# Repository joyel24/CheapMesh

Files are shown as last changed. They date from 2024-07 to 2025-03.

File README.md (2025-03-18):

# CheapMesh
<p>


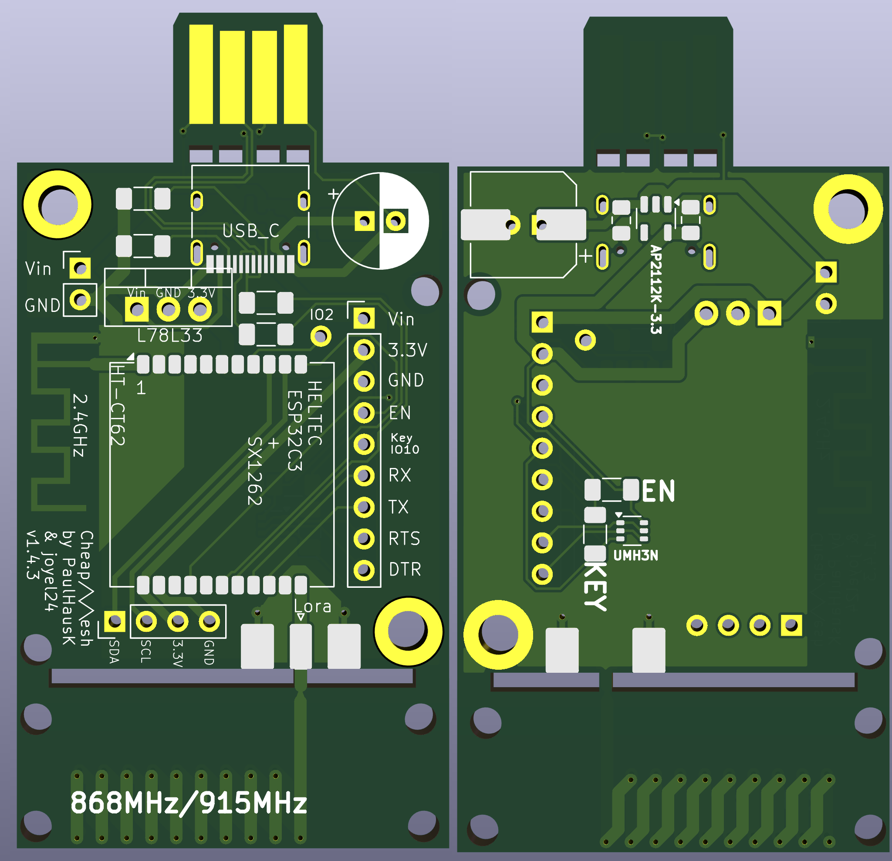
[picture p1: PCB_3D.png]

</p>
CheapMesh is a pcb arround the HT-CT62 chip by Heltec.

The goal is to get a cheap Meshtastic node with this chip, therefore some corners where cut.

Several componemts are implemented double, just pick what works best for you.

## ToDo
- Add CheapMesh variant to Meshtastic firmware

## PCB

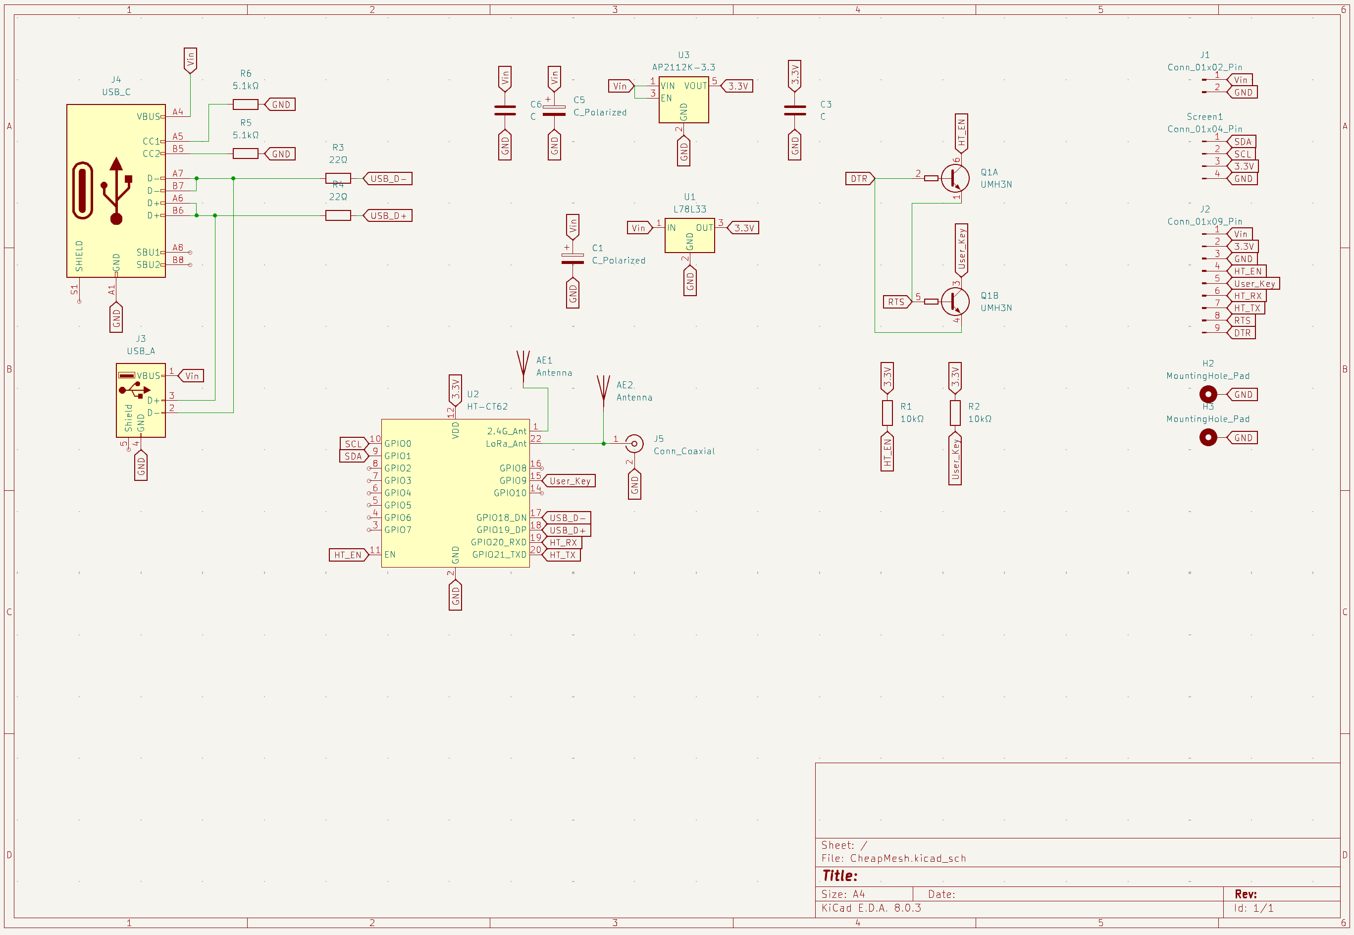
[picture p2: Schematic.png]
Schematic


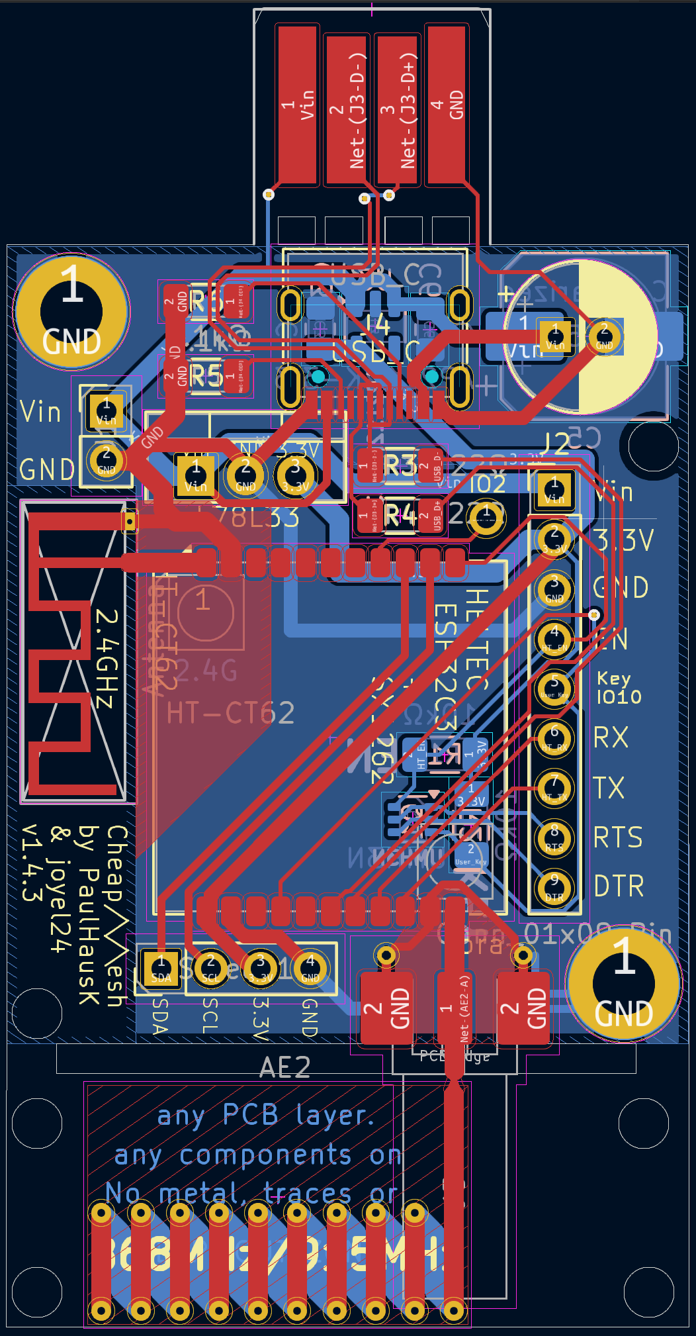
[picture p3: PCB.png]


### Antenna 
* Option A: use the onboard antennas
* Option B: use an external antenna with the IPEX connector (and cutting of the onboard lora antenna)
* Option C: use an external antenna with an sma connector (and cutting of the onboard lora antenna)
* Option D: solder on a dipol antenna (and cutting of the onboard lora antenna)
  
### Screen
* Completele optional. Make sure to get a screen with the matching pinout. I recommend SSD1306 128x64 I2C

### 3.3V Regulator
* Option A: use an external 3.3V powersource
* Option C: use a AP211K-3.3 and the correspondending capacitors
* Option B: use a L78L33 and the correspondending capacitors
* Option D: use a [L78L33 pin compatible DC/DC Buck converter like this one](https://aliexpress.com/item/1005005626634245.html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)
  
### Resetting for flashing
* Option A: populate the UMH3N
* Option B: use an external usb serial interface which can reset the chip
* Option C: Connect GND and HT_EN with a wire. Power on the board (by plugging in) and remove the wire.

### Powering the Board
Never connect more than one powersource at a time!!!
* via the usb a pcb connector
* via the usb c connector 
* via the Vin Pins
* via the 3.3V Pins

### Resistors
All Resitors are 1206 SMD Resistors

R1, R2: Pullup Resistors, 10kOhm

R3, R4: USB Inline Resistors, zero-Ohm

R5, R6: USB-C Resistors, 5,1kOhm

If you want to flash and reflash the HT-CT62 on the pcb, you need to populate R1 and R2.
If you not wanna flash the HT-CT62 on the pcb (you have a already programmed chip), you can make a solder bridge on R1.

## Building instructions
1. Source the the pcb yourself.
2. Solder on the components.
3. Flash the ESP.
    * Option A - use an external usb serial interface like CH34X, CP21XX, FTDI or any other serial interface. 
    * Option B - use the usb A pcb port
    * Option C - use the usb c port (Need to solder it)

## BOM
|Reference|Value |Footprint |Qty|
|---|---|---|---|
|AE1,AE2  |Antenna | |2  |
|C1,C5 |C_Polarized |Depending on power source, +uF if it's instable, optionnal |2  |
|C3,C6 |C |0805 or 2012 metric, value depens on your LDO choice |2  |
|H2,H3 |MountingHole_Pad|3.2mm M3 DIN965 |2  |
|J1 |Conn_01x02_Pin  |Standard 2.54mm headers |2  |
|J2 |Conn_01x09_Pin  |Standard 2.54mm headers |9  |
|J4 |USB_C |TYPE-C-31-M-12 |1  |
|J5 |Conn_Coaxial |SMA 73251-2120 |1  |
|Q1 |UMH3N |SOT-363 |1  |
|R1,R2 |10kΩ |1206 or 3216 metric |2  |
|R3,R4 |0Ω SHUNT |1206 or 3216 metric |2  |
|R5,R6 |5.1kΩ |1206 or 3216 metric |2  |
|Screen1  |Conn_01x04_Pin  |Standard 2.54mm headers |4  |
|IO02 |Conn_01x01_Pin  |Standard 2.54mm headers |1  |
|U1 |L78L33 |TO-220-3 |1  |
|U2 |HT-CT62 |MCU + RF Module: Heltec HT-CT62 |1  |
|U3 |AP2112K-3.3 |SOT-23-5 |1  |

 ## License
 <p xmlns:cc="http://creativecommons.org/ns#" xmlns:dct="http://purl.org/dc/terms/"><span property="dct:title">CheapMesh</span> by <span property="cc:attributionName">PaulHausK</span> is licensed under <a href="https://creativecommons.org/licenses/by-sa/4.0/?ref=chooser-v1" target="_blank" rel="license noopener noreferrer" style="display:inline-block;">Creative Commons Attribution-ShareAlike 4.0 International</a></p>

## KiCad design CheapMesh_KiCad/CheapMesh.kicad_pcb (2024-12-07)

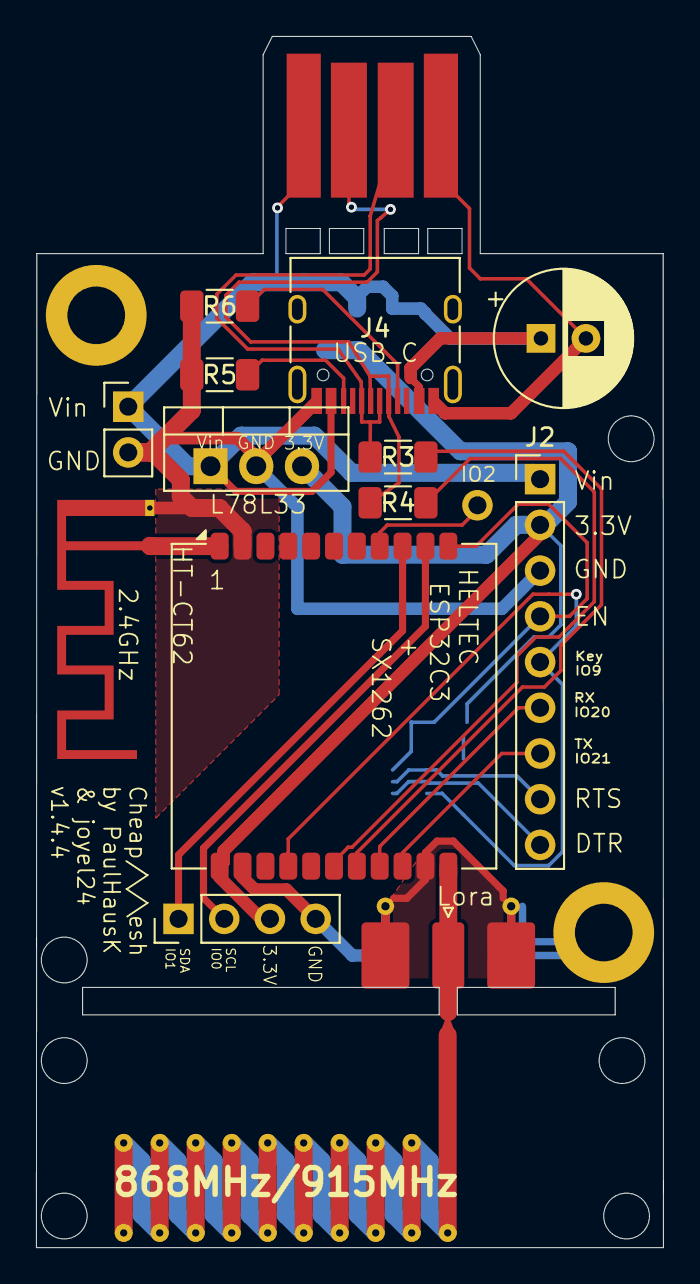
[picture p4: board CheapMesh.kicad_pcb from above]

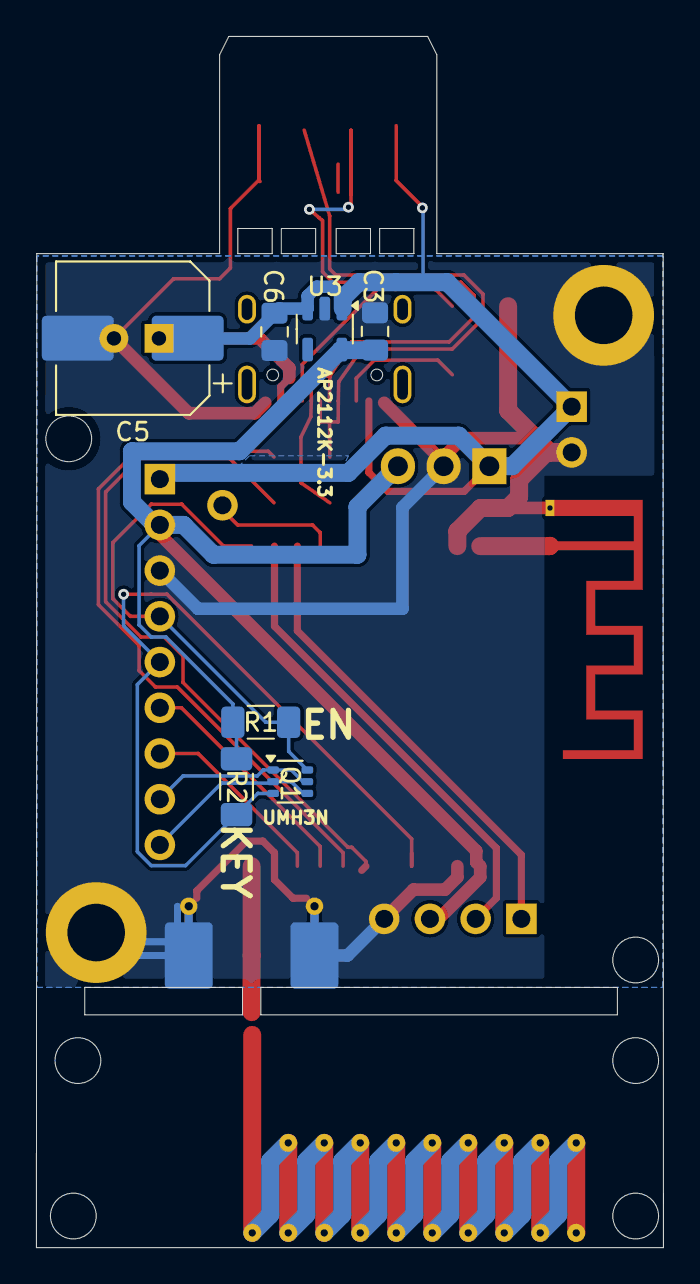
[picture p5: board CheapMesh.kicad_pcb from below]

Board: 2 copper layers, 34.8 x 67.3 mm, 24 parts (7 on the bottom side), 19 nets.

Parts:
AE1: Antenna; Texas_SWRA117D_2.4GHz_Left
AE2: Antenna; Texas_SWRA416_868MHz_915MHz
C1: C_Polarized; CP_Radial_D7.5mm_P2.50mm
C3, C6: C; C_0805_2012Metric_Pad1.18x1.45mm_HandSolder
C5: C_Polarized; CP_Elec_8x6.2
H2, H3: MountingHole_Pad; MountingHole_3.2mm_M3_DIN965_Pad
J1: Conn_01x02_Pin; PinHeader_1x02_P2.54mm_Vertical
J2: Conn_01x09_Pin; PinHeader_1x09_P2.54mm_Vertical
J3: USB_A; usb-PCB
J4: USB_C; USB_C_Receptacle_HRO_TYPE-C-31-M-12
J5: Conn_Coaxial; SMA_Molex_73251-2120_EdgeMount_Horizontal
Q1: UMH3N; SOT-363_SC-70-6
R1, R2: 10kΩ; R_1206_3216Metric_Pad1.30x1.75mm_HandSolder
R3, R4: 22Ω; R_1206_3216Metric_Pad1.30x1.75mm_HandSolder
R5, R6: 5.1kΩ; R_1206_3216Metric_Pad1.30x1.75mm_HandSolder
Screen1: Conn_01x04_Pin; PinHeader_1x04_P2.54mm_Vertical
U1: L78L33; TO-220-3_Vertical
U2: HT-CT62; Heltec_HT-CT62
U3: AP2112K-3.3; SOT-23-5

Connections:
3.3V: C3.1, J2.2, R1.1, R2.1, Screen1.3, U1.3 (OUT), U2.12 (VDD), U3.5 (VOUT)
DTR: J2.9, Q1.2 (B1), Q1.4 (E2)
GND: C1.2, C3.2, C5.2, C6.2, H2.1, H3.1, J1.2, J2.3, J3.4 (GND), J4.A1 (GND), J4.A12 (GND), J4.B1 (GND), J4.B12 (GND), J5.2 (Ext), R5.2, R6.2, Screen1.4, U1.2 (GND), U2.2 (GND), U2.13 (GND), U2.21 (GND), U3.2 (GND)
HT_EN: J2.4, Q1.6 (C1), R1.2, U2.11 (EN)
HT_RX: J2.6, U2.19 (GPIO20_RXD)
HT_TX: J2.7, U2.20 (GPIO21_TXD)
unnamed: AE1.1 (A), U2.1 (2.4G_Ant)
unnamed: AE2.1 (A), J5.1 (In), U2.22 (LoRa_Ant)
unnamed: J3.3 (D+), J4.A6 (D+), J4.B6 (D+), R3.1
unnamed: J3.2 (D-), J4.A7 (D-), J4.B7 (D-), R4.1
unnamed: J4.A5 (CC1), R6.1
unnamed: J4.B5 (CC2), R5.1
RTS: J2.8, Q1.1 (E1), Q1.5 (B2)
SCL: Screen1.2, U2.10 (GPIO0)
SDA: Screen1.1, U2.9 (GPIO1)
USB_D+: R3.2, U2.18 (GPIO19_DP)
USB_D-: R4.2, U2.17 (GPIO18_DN)
User_Key: J2.5, Q1.3 (C2), R2.2, U2.15 (GPIO9)
Vin: C1.1, C5.1, C6.1, J1.1, J2.1, J3.1 (VBUS), J4.A4 (VBUS), J4.A9 (VBUS), J4.B4 (VBUS), J4.B9 (VBUS), U1.1 (IN), U3.1 (VIN), U3.3 (EN)

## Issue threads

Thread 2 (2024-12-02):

wrong ht-ct62 footprint

joyel24, 2024-12-02:
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

Closed 2024-12-07.

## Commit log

2024-07-03 kicad autoUpdate, no changes
    [CheapMesh.kicad_pcb, CheapMesh.kicad_sch]
2024-07-03 invert USB_D+ USB_D- in schematics
    [CheapMesh.kicad_sch]
2024-07-03 invert USB_D+ USB_D- in pcb
    [CheapMesh.kicad_pcb]
2024-10-20 add gpio2 pin
    [CheapMesh.kicad_pcb]
2024-10-20 update pcb PNG
2024-12-07 fix HT-CT62 footprint
    [CheapMesh.kicad_pcb]
2024-12-07 fix D+/- circuit
    [CheapMesh.kicad_pcb]
2024-12-07 GPIO num visible on PC
    [CheapMesh.kicad_pcb]
2024-12-07 update version
    [CheapMesh.kicad_pcb]
